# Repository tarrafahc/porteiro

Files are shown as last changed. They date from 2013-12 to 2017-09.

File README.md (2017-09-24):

porteiro
========

Repositório do porteiro do Tarrafa

O que é?
--------

O porteiro é o programa que roda no mula-sem-cabeça e serve principalmente para avisar quando tem ou não gente no Tarrafa. O porteiro centraliza várias funções. São elas: botão de presença, painel de LEDs, tomadas controladas por relé (pra ninguém esquecer a cafeteira ligada) e 'mood lamp'.

Estrutura dos arquivos
----------------------

A pasta 'arduino' tem o código que roda na plaquinha de arduino do porteiro. Este código atualiza o painel de LEDs com informação vinda pela serial, manda informação de alteração do estado do botão pela serial e controla a tomada e o 'mood lamp'.

A pasta 'eagle' tem os esquemáticos e o layout da plaquinha do shield de arduino do porteiro.

A pasta 'fonte' contém a fonte criada colaborativamente pelo Tarrafa para mostrar coisas no painel.

O script 'porteiro.py' roda no mula-sem-cabeça e fica mandando texto para o painel de LEDs e lendo informação do botão de presença.

Botão
-----

O botão deve ser pressionado pela primeira pessoa que entra no Tarrafa e pela última pessoa que sai do Tarrafa. Ao ligar, o botão manda uma mensagem para o mula-sem-cabeça para que ele atualize o status online do Tarrafa e acende a tomada controlada. Ao desligar, o botão manda novamente a mensagem para o mula-sem-cabeça e prepara a tomada para ser desligada.

Tomada controlada
-----------------

Na tomada controlada ficam ligadas (por enquanto) a luz externa do Tarrafa e a cafeteira. A tomada desliga um minuto depois de o botão ser desligado, dando tempo para que a luz externa ilumine a porta enquanto ela é fechada. A cafeteira também é desligada automaticamente para ninguém esquecer de desligá-la...

Painel de LEDs
--------------

O painel de LEDs foi reutilizado de alguma sucata. Durante encontros da N.E.R.D., foi feita a engenharia reversa do circuito eletrônico e foi feita uma interface para controlá-lo pelo Arduino. O painel tem 10 matrizes de 7x5 LEDs verdes/vermelhos. Dá pra passar qualquer coisa nos 10 caracteres do painel, mas no momento o que passa é a data, a hora e alguma mensagem de auto-ajuda qualquer...

Mood Lamp
---------

A 'mood lamp' fica ligada enquanto tem gente no Tarrafa. As cores da lâmpada ficam variando aleatoriamente num LED RGB.

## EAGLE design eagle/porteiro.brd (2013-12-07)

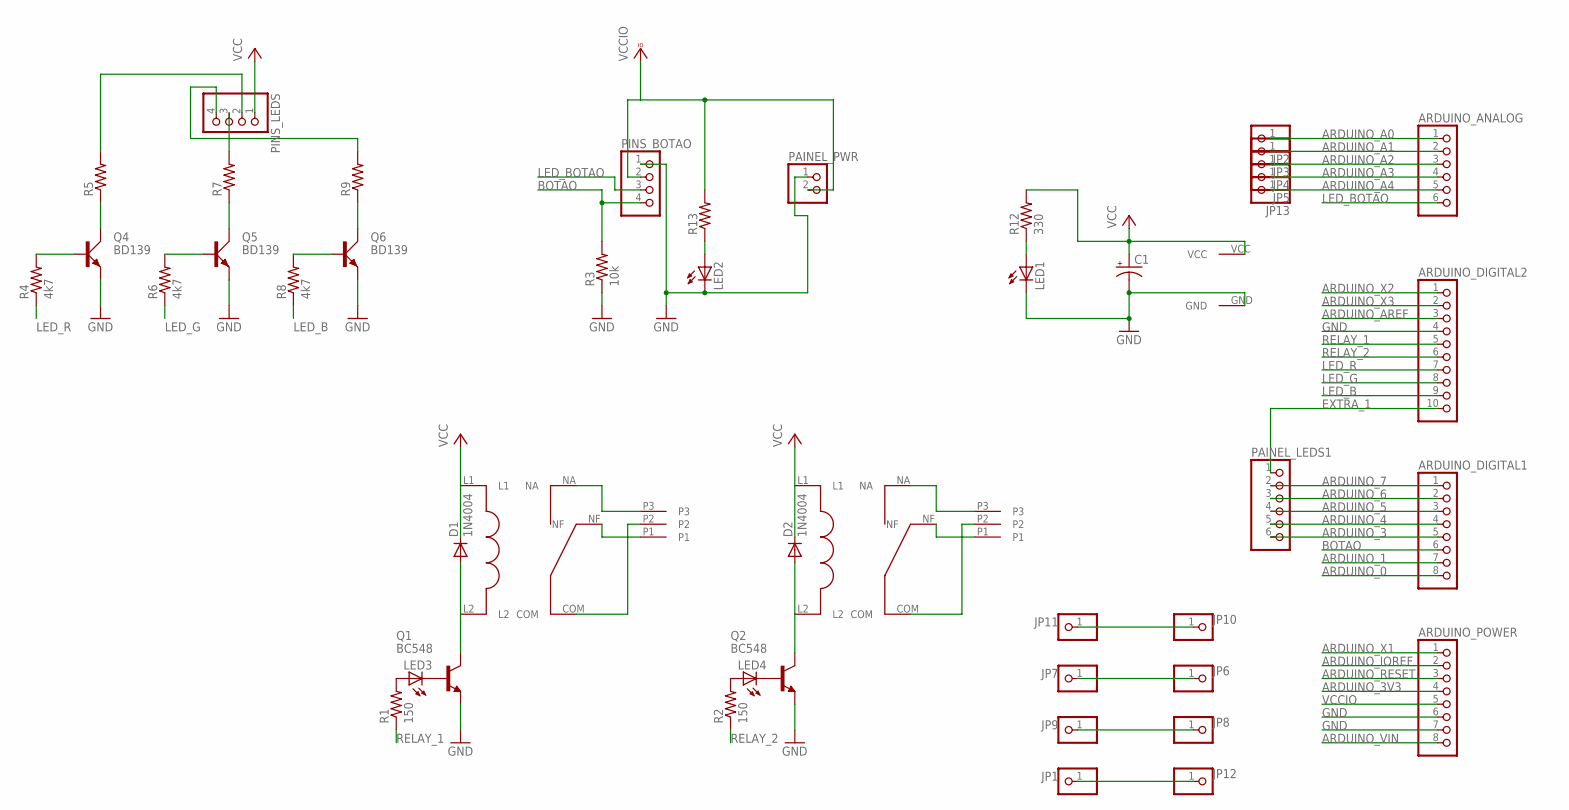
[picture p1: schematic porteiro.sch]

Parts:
ARDUINO_ANALOG: PINHD-1X6; 1X06
ARDUINO_DIGITAL1: PINHD-1X8; 1X08
ARDUINO_DIGITAL2: PINHD-1X10; 1X10
ARDUINO_POWER: PINHD-1X8; 1X08
C1: CPOL-USE5-10.5; E5-10,5
D1, D2: 1N4004; DO41-10
JP1, JP2, JP3, JP4, JP5, JP6, JP7, JP8, JP9, JP10, JP11, JP12, JP13: PINHD-1X1; 1X01
LED1, LED2, LED3, LED4: LED5MM
PAINEL_LEDS1: PINHD-1X6; 1X06
PAINEL_PWR: PINHD-1X2; 1X02
PINS_BOTAO: PINHD-1X4; 1X04
PINS_LEDS: PINHD-1X4; 1X04
Q1, Q2: BC548; TO92-EBC
Q4, Q5, Q6: BD139; TO126AV
R1, R2: 150; 0207/10
R3: 10k; 0207/7
R4, R6, R8: 4k7; 0207/10
R5, R7, R9: R-US_0411/15; 0411/15
R12: 330; 0207/10
R13: R-US_0207/7; 0207/7
U$1, U$3: RELAY
U$2, U$4: KRE3
U$7: DC

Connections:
ARDUINO_0: ARDUINO_DIGITAL1.8
ARDUINO_1: ARDUINO_DIGITAL1.7
ARDUINO_3: ARDUINO_DIGITAL1.5, PAINEL_LEDS1.6
ARDUINO_3V3: ARDUINO_POWER.4
ARDUINO_4: ARDUINO_DIGITAL1.4, PAINEL_LEDS1.5
ARDUINO_5: ARDUINO_DIGITAL1.3, PAINEL_LEDS1.4
ARDUINO_6: ARDUINO_DIGITAL1.2, PAINEL_LEDS1.3
ARDUINO_7: ARDUINO_DIGITAL1.1, PAINEL_LEDS1.2
ARDUINO_A0: ARDUINO_ANALOG.1, JP2.1
ARDUINO_A1: ARDUINO_ANALOG.2, JP3.1
ARDUINO_A2: ARDUINO_ANALOG.3, JP4.1
ARDUINO_A3: ARDUINO_ANALOG.4, JP5.1
ARDUINO_A4: ARDUINO_ANALOG.5, JP13.1
ARDUINO_AREF: ARDUINO_DIGITAL2.3
ARDUINO_IOREF: ARDUINO_POWER.2
ARDUINO_RESET: ARDUINO_POWER.3
ARDUINO_VIN: ARDUINO_POWER.8
ARDUINO_X1: ARDUINO_POWER.1
ARDUINO_X2: ARDUINO_DIGITAL2.1
ARDUINO_X3: ARDUINO_DIGITAL2.2
BOTAO: ARDUINO_DIGITAL1.6, PINS_BOTAO.4, R3.2
EXTRA_1: ARDUINO_DIGITAL2.10, PAINEL_LEDS1.1
GND: ARDUINO_DIGITAL2.4, ARDUINO_POWER.6, ARDUINO_POWER.7, C1.-, LED1.K (C), LED2.K (C), PAINEL_PWR.1, PINS_BOTAO.1, Q1.E, Q2.E, Q4.E, Q5.E, Q6.E, R3.1, U$7.GND
LED_B: ARDUINO_DIGITAL2.9, R8.1
LED_BOTAO: ARDUINO_ANALOG.6, PINS_BOTAO.3
LED_G: ARDUINO_DIGITAL2.8, R6.1
LED_R: ARDUINO_DIGITAL2.7, R4.1
unnamed: U$1.NF, U$2.P1
unnamed: D1.A, Q1.C, U$1.L2
unnamed: LED3.K (C), Q1.B
unnamed: U$1.NA, U$2.P3
unnamed: U$1.COM, U$2.P2
unnamed: D2.A, Q2.C, U$3.L2
unnamed: LED3.A, R1.2
unnamed: LED4.K (C), Q2.B
unnamed: U$3.NA, U$4.P3
unnamed: U$3.COM, U$4.P2
unnamed: JP1.1, JP12.1
unnamed: LED4.A, R2.2
unnamed: U$3.NF, U$4.P1
unnamed: Q4.B, R4.2
unnamed: Q4.C, R5.1
unnamed: PINS_LEDS.2, R5.2
unnamed: Q5.B, R6.2
unnamed: Q5.C, R7.1
unnamed: PINS_LEDS.3, R7.2
unnamed: Q6.B, R8.2
unnamed: Q6.C, R9.1
unnamed: PINS_LEDS.4, R9.2
unnamed: LED1.A, R12.1
unnamed: LED2.A, R13.1
RELAY_1: ARDUINO_DIGITAL2.5, R1.1
RELAY_2: ARDUINO_DIGITAL2.6, R2.1
VCC: C1.+, D1.C, D2.C, PINS_LEDS.1, R12.2, U$1.L1, U$3.L1, U$7.VCC
VCCIO: ARDUINO_POWER.5, PAINEL_PWR.2, PINS_BOTAO.2, R13.2
XTRA_1: JP10.1, JP11.1
XTRA_2: JP6.1, JP7.1
XTRA_3: JP8.1, JP9.1

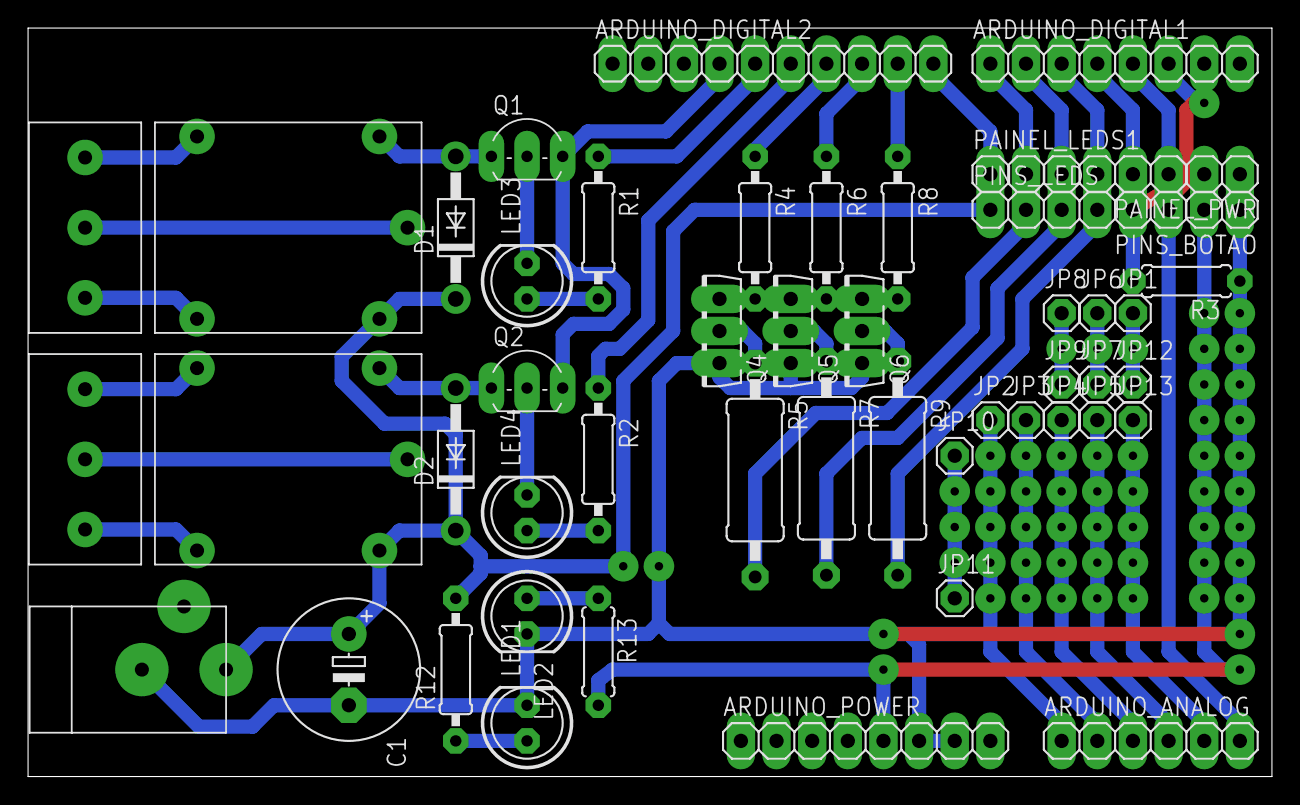
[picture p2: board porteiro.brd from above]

Board: 2 copper layers, 88.6 x 53.3 mm, 49 parts (0 on the bottom side), 48 nets.

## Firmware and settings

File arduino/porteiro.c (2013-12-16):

#define F_CPU 16000000
#define BAUD  9600

#define MYUBRR (F_CPU/16/BAUD-1)

#include <avr/io.h>
#include <avr/interrupt.h>
#include <avr/pgmspace.h>
#include <avr/eeprom.h>
#include <avr/sleep.h>

struct pino {
    volatile uint8_t *dir;
    volatile uint8_t *pin;
    volatile uint8_t *port;
    uint8_t bit;
};

static const struct pino _4015_d   = { &DDRB, &PINB, &PORTB, 0 }; /* marrom branco     */
static const struct pino _4015_clk = { &DDRD, &PIND, &PORTD, 7 }; /* verde  branco     */
static const struct pino _4015_mr  = { &DDRD, &PIND, &PORTD, 4 }; /* azul              */

static const struct pino _4094_clk = { &DDRD, &PIND, &PORTD, 6 }; /* marrom            */
static const struct pino _4094_str = { &DDRD, &PIND, &PORTD, 5 }; /* azul   branco     */
static const struct pino _4094_d   = { &DDRB, &PINB, &PORTB, 0 }; /* marrom branco [2] */
static const struct pino _4094_oe  = { &DDRD, &PIND, &PORTD, 3 }; /* verde             */

static const struct pino botao     = { &DDRD, &PIND, &PORTD, 2 }; /* botao             */
static const struct pino botao_led = { &DDRC, &PINC, &PORTC, 5 }; /* led do botao      */

static const struct pino rele_1    = { &DDRB, &PINB, &PORTB, 4 }; /* rele 1            */
static const struct pino rele_2    = { &DDRB, &PINB, &PORTB, 5 }; /* rele 2            */

static inline void set_output  (const struct pino *p) { *p->dir  |=  (1<<p->bit); }
static inline void set_input   (const struct pino *p) { *p->dir  &= ~(1<<p->bit); }
static inline void ligar_bit   (const struct pino *p) { *p->port |=  (1<<p->bit); }
static inline void desligar_bit(const struct pino *p) { *p->port &= ~(1<<p->bit); }
static inline uint8_t ler_bit  (const struct pino *p) { return *p->pin & (1<<p->bit); }
static inline void clk_d       (const struct pino *clk, const struct pino *d, uint8_t val)
{
    desligar_bit(clk);
    if (val) ligar_bit(d);
    else  desligar_bit(d);
    ligar_bit(clk);
}

static const struct pino pino_r = { &DDRB, &PINB, &PORTB, 1 }; /* led vermelho      */
static const struct pino pino_g = { &DDRB, &PINB, &PORTB, 3 }; /* led verde         */
static const struct pino pino_b = { &DDRB, &PINB, &PORTB, 2 }; /* led azul          */
static volatile uint8_t *led_r  = &OCR1AL;              /* led vermelho      */
static volatile uint8_t *led_g  = &OCR2A ;              /* led verde         */
static volatile uint8_t *led_b  = &OCR1BL;              /* led azul          */
static uint8_t cur_r = 0;
static uint8_t cur_g = 0;
static uint8_t cur_b = 0;

/* this is a cheap random number generator */
static uint8_t cheap_rand(void)
{
    static uint16_t state;
    state = state * 25173 + 13849;
    return state>>7;
}

extern PROGMEM uint8_t fonte[0x100][7];

static uint8_t out_buf[7][7] = {{0}}; /* [linha][50 bits] */
static uint8_t out_idx       =   0  ;

static void
print_char(uint8_t c, uint8_t pos)
{
    uint8_t letra[4] = { pgm_read_byte_near(&fonte[c][0]),
                         pgm_read_byte_near(&fonte[c][1]),
                         pgm_read_byte_near(&fonte[c][2]),
                         pgm_read_byte_near(&fonte[c][3]) };
    uint8_t linhas[7] = { letra[0] >> 4, letra[0] & 0x0F,
                          letra[1] >> 4, letra[1] & 0x0F,
                          letra[2] >> 4, letra[2] & 0x0F,
                          letra[3] >> 4 };
    uint8_t d[2] = { pos >> 3, (pos + 3) >> 3 };
    uint8_t q[2] = { pos  & 7, (8 - pos)  & 7 };
    uint8_t mask[2] = { 0xff & ~(0x0f << q[0]), 0xff << (q[0]-4) };

    for (uint8_t i = 0; i < 7; i++) {
        out_buf[i][d[0]] = (out_buf[i][d[0]] & mask[0]) | (linhas[i] << q[0]);
        if (d[0] != d[1])
            out_buf[i][d[1]] = (out_buf[i][d[1]] & mask[1]) | (linhas[i] >> q[1]);
    }
}

static void
init_button()
{
    EICRA = (1 << ISC01); /* falling edge */
    EIMSK = (1 << INT0);
}

static void
init_serial()
{
    UBRR0H = MYUBRR >> 8;
    UBRR0L = MYUBRR;
    UCSR0C = (1 << UCSZ00) | (1 << UCSZ01); /* 8-bit */
    /* enable rx, tx, and USART_RX interrupt */
    UCSR0B = (1 << RXEN0 ) | (1 << TXEN0 ) | (1 << RXCIE0);
}

static void
init_timer()
{
    /* timer0 = main timer */
    TCCR0A = 0;                         /* normal port operation */
    TCCR0B = (1 << CS01) | (1 << CS00); /* prescaler = 64 */
    TIFR0  = (1 << TOV0);               /* clear pending interrupts */
    TIMSK0 = (1 << TOIE0);              /* enable TIMER0_OVF interrupt */
}

static void
init_pwm()
{
    /* pwm on arduino pins 9 and 10 */
    /* phase-correct pwm, 8-bit, OC1A and OC1B */
    TCCR1A = (1 << WGM10) | (1 << COM1A1) | (1 << COM1B1);
    TCCR1B = (1 << CS10); /* prescaler = 1 */

    /* pwm on arduino pin 11 */
    /* phase-correct pwm, 8-bit, OC2A */
    TCCR2A = (1 << WGM20) | (1 << COM2A1);
    TCCR2B = (1 << CS20); /* prescaler = 1 */
}

static void loop()
{
    /* no loop, just sleep =) */
    set_sleep_mode(SLEEP_MODE_IDLE);
    sleep_enable();
    sleep_mode();
    /* dormindo */
    sleep_disable();
}

static uint8_t status_ee EEMEM = 0;
static uint8_t status = 0;

static void
do_status(void)
{
    if (!status) {
        desligar_bit(&botao_led);
        *led_r = 255;
        *led_g = 255;
        *led_b = 255;
    } else {
        ligar_bit(&botao_led);
        ligar_bit(&rele_1);
        ligar_bit(&rele_2);
    }
}

void main(void) __attribute__((noreturn));
void main()
{
    init_button();
    init_serial();
    init_timer();
    init_pwm();
    sei();  /* enable interrupts */

    set_output(&_4015_d  );
    set_output(&_4015_clk);
    set_output(&_4015_mr );
    set_output(&_4094_clk);
    set_output(&_4094_str);
    set_output(&_4094_d  );
    set_output(&_4094_oe );

    set_output(&pino_r);
    set_output(&pino_g);
    set_output(&pino_b);

    set_input (&botao    );
    set_output(&botao_led);

    set_output(&rele_1);
    set_output(&rele_2);

    status = eeprom_read_byte(&status_ee);
    do_status();

    desligar_bit(&_4015_mr);
    ligar_bit(&_4094_oe);
    while (1)
        loop();
}

static uint8_t painel_red   = 1;
static uint8_t painel_green = 0;

static uint16_t turnoff_count = 0;
static uint8_t debounce_count = 0;

/* main timer interrupt: F_CPU / (256 * 64) = 976.5625 Hz, 1.024 ms */
ISR(TIMER0_OVF_vect)
{
    /* atualizar uma linha do painel */
    static uint8_t i = 0;
    desligar_bit(&_4094_str);
    for (uint8_t j = 0; j < 50; j++)
        clk_d(&_4094_clk, &_4094_d, ((out_buf[i][j>>3]>>(j&7))&1));
    desligar_bit(&_4094_oe);
    ligar_bit(&_4094_str);
    for (uint8_t j = 0; j < 7; j++) {
        clk_d(&_4015_clk, &_4015_d, (j==i)&painel_red  );
        clk_d(&_4015_clk, &_4015_d, (j==i)&painel_green);
    }
    clk_d(&_4015_clk, &_4015_d, 0);
    ligar_bit(&_4094_oe);
    if (++i == 7)
        i = 0;

    /* conferir debounce do botão */
    if (debounce_count) {
        debounce_count--;
        if (!debounce_count && ler_bit(&botao)) {
            /* 51.2 ms debounce */
            status = !status;
            do_status();
            if (!status)
                turnoff_count = 0xffff;
            eeprom_write_byte(&status_ee, status);
            UDR0 = status + '0';
        }
    }

    if (!status) {
        /* conferir tempo de desligamento */
        if (turnoff_count) {
            turnoff_count--;
            if (!turnoff_count) {
                /* 67.10784s delay */
                desligar_bit(&rele_1);
                desligar_bit(&rele_2);
                *led_r = 0;
                *led_g = 0;
                *led_b = 0;
            }
        }
    } else {
        /* pseudo-mood lamp */
        static uint8_t led_count = 0;

        if (++led_count == 10) {
            uint8_t old_r = *led_r;
            uint8_t old_g = *led_g;
            uint8_t old_b = *led_b;
            if (old_r == cur_r && old_g == cur_g && old_b == cur_b) {
                cur_r = cheap_rand();
                cur_g = cheap_rand();
                cur_b = cheap_rand();
            }
            if (old_r > cur_r) *led_r -= 1; else if (old_r < cur_r) *led_r += 1;
            if (old_g > cur_g) *led_g -= 1; else if (old_g < cur_g) *led_g += 1;
            if (old_b > cur_b) *led_b -= 1; else if (old_b < cur_b) *led_b += 1;
            led_count = 0;
        }
    }
}

/* usart rx interrupt */
ISR(USART_RX_vect)
{
    /* gravar caractere recebido na posição atual do buffer do painel */
    print_char(UDR0, out_idx++ * 5);
    if (out_idx == 10)
        out_idx = 0;
}

/* button interrupt */
ISR(INT0_vect)
{
    /* inicializar contagem de debounce */
    debounce_count = 50;
}

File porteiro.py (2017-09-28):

#!/usr/bin/python
# -*- coding: utf-8 -*-

import urllib2
import serial
import json
import time
import os
from twython import Twython

f = open('twitter_keys', 'r')
APPKEY = f.readline().rstrip('\n')
APP_SECRET = f.readline().rstrip('\n')
OAUTH_TOKEN =  f.readline().rstrip('\n')
OAUTH_TOKEN_SECRET = f.readline().rstrip('\n')
f.close()

twitter = Twython(APPKEY, APP_SECRET, OAUTH_TOKEN, OAUTH_TOKEN_SECRET)

def aberto():
    print "Tarrafa is on"
    #os.system("ssh -p 2022 tarrafahc@direct.tarrafa.net 1")
    os.system("../botaobiarra/changeisgood.sh aberto")
    twitter.update_status(status='[%02d/%02d/%4d %02d:%02d:%2d] O #tarrafa está aberto! :D' % (lt.tm_mday, lt.tm_mon, lt.tm_year, lt.tm_hour, lt.tm_min, lt.tm_sec ))

def fechado():
    print "Tarrafa is off"
    #os.system("ssh -p 2022 tarrafahc@direct.tarrafa.net 0")
    os.system("../botaobiarra/changeisgood.sh fechado")
    twitter.update_status(status='[%02d/%02d/%4d %02d:%02d:%2d] O #tarrafa está fechado. :(' % (lt.tm_mday, lt.tm_mon, lt.tm_year, lt.tm_hour, lt.tm_min, lt.tm_sec ))

# Lê um byte da serial pelo Arduino. Se tiver algum dado, atualiza o servidor.
def botao():
    bytes = ser.read(1)
    if bytes:
        if   bytes is '1':
            aberto()
        elif bytes is '0':
            fechado()

# Abrir a porta serial do Arduino em 9600 baud com tempo de espera de 1
# segundo. O tempo de espera é usado na função de leitura para não precisar
# fazer o código dormir explicitamente.
ser = serial.Serial('/dev/ttyUSB0', baudrate=9600, timeout=1)

# Esperar 2 segundos caso o Arduino queira reiniciar.
time.sleep(2)

# Loop principal do painel.
while True:
    # Mostrar texto de arquivo
    text = ""
    try:
        fp = open('text', 'r')
        text = "%10s" % (fp.read())
        fp.close()
    except IOError:
        pass

    if text != "":
        ser.write(text)
        botao()

    # Mostrar hora
    lt = time.localtime()
    ser.write("  %02d:%02d:%02d" % (lt.tm_hour, lt.tm_min, lt.tm_sec))
    # Mostrar data
    ser.write("%02d/%02d/%4d" % (lt.tm_mday, lt.tm_mon, lt.tm_year))
    botao()
    time.sleep(2)
    
# Mostrar temperatura
    # TODO pegar uma vez por hora ou coisa parecida
#    url = 'http://api.openweathermap.org/data/2.5/weather?q=florianopolis'
#    temp = json.loads(urllib2.urlopen(url).read())['main']['temp']-273.15
#    ser.write("   %.4g C" % (temp))

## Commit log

2013-10-07 arduino: remover Serial.println() de depuração
2013-10-07 arduino: reduzir loops
2013-10-09 arduino: usar index para buffer de texto
2013-10-09 programa: largar arduino, escrever direto em C
2013-12-06 programa: expandir seleção de bits em DDRC
2013-12-06 programa: ajustar pinos para placa nova
    - Configurar pinos individualmente;
    - Usar funções inline no lugar de macros;
    - Atualizar numero dos pinos e suas portas.
2013-12-06 programa: remover buffer de texto
2013-12-06 programa: documentar frequencia do main timer
2013-12-07 Makefile: mudar gravador para Arduino Duemilanove
2013-12-07 eagle: adicionar
    [botao.brd, botao.sch]
2013-12-07 renomear LEDs para arduino
2013-12-07 script: mover arquivo para o root
2013-12-16 script: remover temperatura
2013-12-16 script: esperar reset do arduino
2014-01-05 painel: esperar 2 segundos para dar tempo ao arduino
2014-01-05 renomear painel para porteiro
2014-01-05 renomear LEDs para porteiro
2014-01-05 eagle: renomear botao para porteiro
    [porteiro.brd, porteiro.sch]
2017-09-24 adicionadas as funções de tweet e de mudança da imagem no botaobiarra
